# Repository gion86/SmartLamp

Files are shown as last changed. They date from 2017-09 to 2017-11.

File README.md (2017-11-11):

# SMART LAMP
### Smart lamp to wakeup with sunrise
##### Through hole version

The project is a LED strip control board to generate a smart wakeup light, which 
simulates the sunrise light.
On board there is a real time clock, to  keep track of the actual date and time 
even on power loss, and some MOSFET to drive the LEDs with PWM.
On a separate breakout board I'm using a BLE chipset to connect with an Android 
application, to setup date, time, alarms and LED light.

Everything is soldered on the same PCB. The micro is an Atmel ATTiny84.

The project is compiled for Atmel AVR, with standard AVR GCC toolchain. 
Eclipse was used to create and compile the projects, with the AVR Eclipse Plugin.

This project consists of a main C++ file and some libraries:

* **DS3232RTC** : real time clock library, to read the actual date and time. The sensors 
  library have been modified to work with the an external instance of the I2C bus 
  control class, and each functionality has been tested with the hardware. 
* **TimeZone** : Arduino library to account for DST (summer time) with the RTC clock. 
  The timezone rules are saved into an EEPROM image (to save program memory on the 
  ATTiny84): the image is in Intel HEX format.
  (reference <https://github.com/gion86/Timezone>, version with time.h from avr-libc).
* **USIWire** : Wire library for the small ATTiny, were the I2C management 
  hardware is not present. The library uses the internal USI hardware to communicate 
  over serial connection, and implement I2C protocol (reference <https://github.com/puuu/USIWire>).
* **ATTiny core**  (reference <https://github.com/gion86/ATTinyCore/tree/newduino> and 
  <https://github.com/SpenceKonde/ATTinyCore>)

The project folder contains:

* the bill of material;
* datasheet of used components;
* electrical schematic and board (made with Eagle);

Some pictures can be found at https://photos.app.goo.gl/nYQq9dkLF3Ui9xUt2

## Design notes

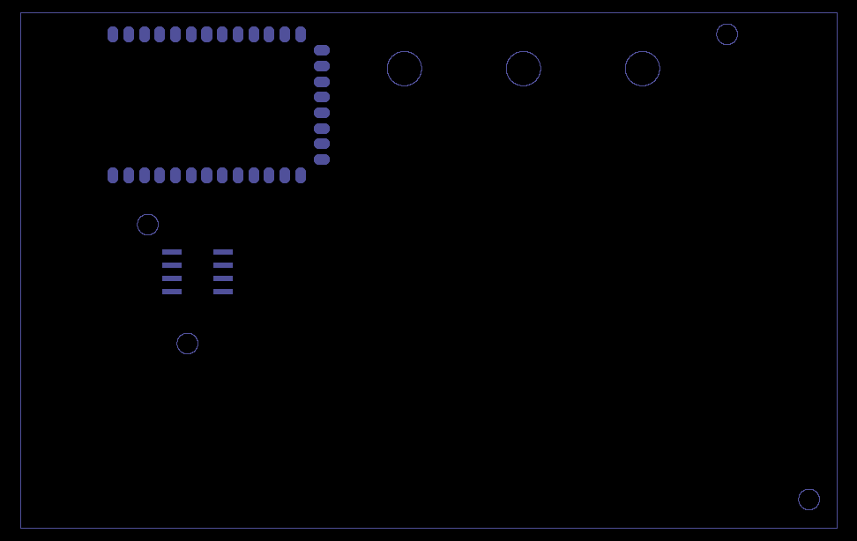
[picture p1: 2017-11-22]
Documentation/Schematics/SmartLamp/Gerber/PNGs/SmartLamp.GTP.png

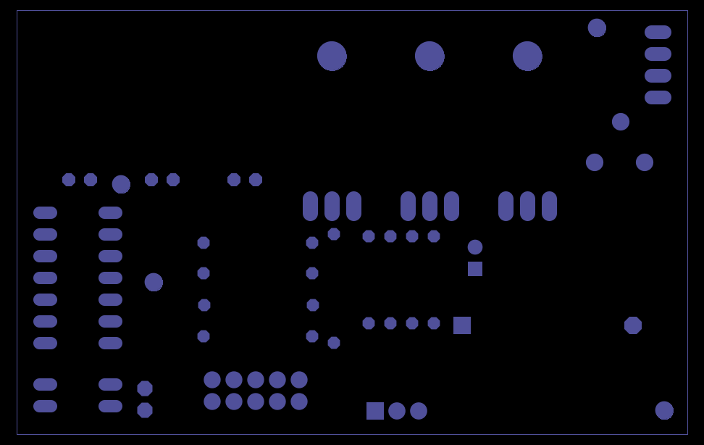
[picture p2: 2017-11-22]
Documentation/Schematics/SmartLamp/Gerber/PNGs/SmartLamp.GBS.png

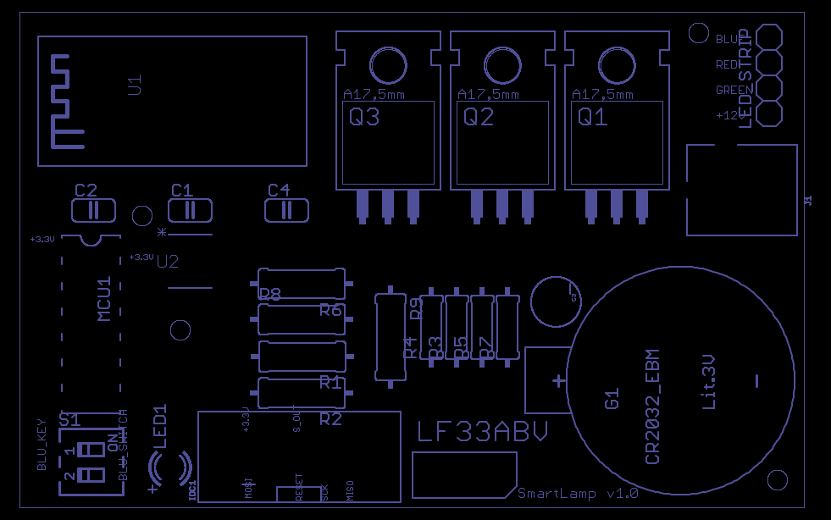
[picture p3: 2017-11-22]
Documentation/Schematics/SmartLamp/Gerber/PNGs/SmartLamp.GTO.png

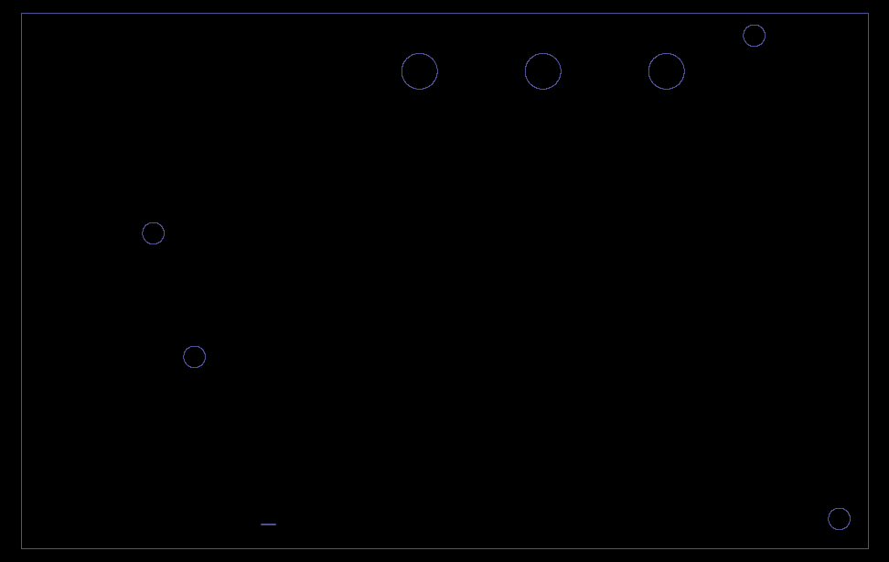
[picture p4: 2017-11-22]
Documentation/Schematics/SmartLamp/Gerber/PNGs/SmartLamp.GBO.png

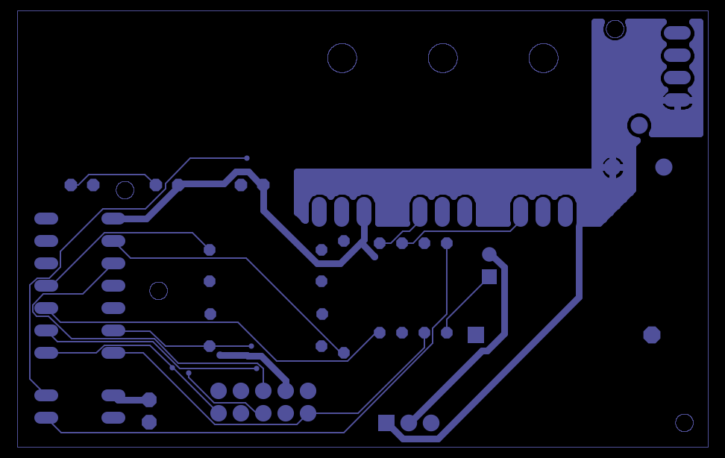
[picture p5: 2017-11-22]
Documentation/Schematics/SmartLamp/Gerber/PNGs/SmartLamp.GBL.png

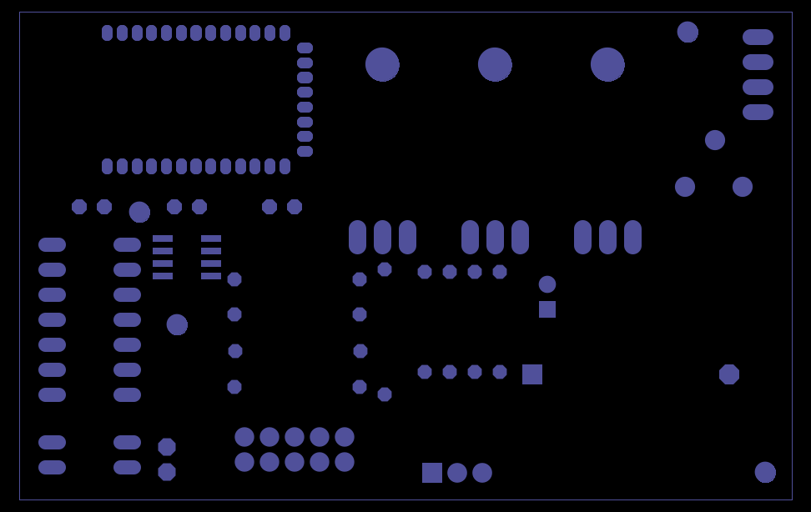
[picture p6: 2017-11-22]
Documentation/Schematics/SmartLamp/Gerber/PNGs/SmartLamp.GTS.png

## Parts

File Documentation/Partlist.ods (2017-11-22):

SMART LAMP - PROJECT BOM
Component | Value | Device | Package |  | Where | Price | Shipment Cost
Electronic
BT1 | BT1 | BATTERY-20MM_SMD_4LEGS | BATTCON_20MM_4LEGS | x | Amazon | € 0,18
BATTERY CR2032 |  |  |  | x
C1 | 0.1uF | C-US025-024X044 | C025-024X044 | x
C2 | 0.1uF | C-US025-024X044 | C025-024X044 | x
C4 | 0.1uF | C-US025-024X044 | C025-024X044 | x
C3 | 100uF | CAP_POLPTH2 | CPOL-RADIAL-10UF-25V | x
IC1 | DS3231/SO | DS3231/SO | SO16W | x | Maxim
IDC1 | IDC1 | CONN_05X2SHD | 2X5-SHROUDED | x
J1 | POWER_JACKPTH_BREAD | POWER_JACKPTH_BREAD | POWER_JACK_PTH_BREAD | x | Ebay | € 0,50
LED1 | GREEN | LED3MM | LED3MM | x
LF33ABV | LF33ABV | LF33ABV | TO254P450X1020X1935-3P | x
MCU1 | ATTINY84ATTINY84-20PU | ATTINY84ATTINY84-20PU | DIL14 | x
MCU SOCKET |  | 14 PIN DIP | 14 PIN DIP | x
Q1 | IRL44Z | IRL44Z | TO220BH | x | Ebay | € 1,30 | € 5,50
Q2 | IRL44Z | IRL44Z | TO220BH | x | Ebay | € 1,30
Q3 | IRL44Z | IRL44Z | TO220BH | x | Ebay | € 1,30
R1 | 10K | R-US_0309/12 | 0309/12 | x
R2 | 10K | R-US_0309/12 | 0309/12 | x
R3 | 220 | R-US_0207/10 | 0207/10 | x
R4 | 220 | R-US_0207/10 | 0207/10 | x
R5 | 220 | R-US_0207/10 | 0207/10 | x
R6 | 10K | R-US_0309/12 | 0309/12 | x
R7 | 1K | R-US_0207/10 | 0207/10 | x
R8 | 470 | R-US_0309/12 | 0309/12 | x
S1 | SD4-02 | SD4-02 | DIL/CODE SWITCH | x | Ebay | € 1,00
U1 | HM-10 | HM-10 | HM-10 |  | Ebay | € 1,89 | € 2,99
BOARD |  | PCB |  |  |  | € 4,50 | € 5,77
Construction
LED STRIP RGB | RGB 5050 5mt |  |  | x | Ebay | € 7,92 | € 7,00
LED STRIP CONNECTOR | Jack 4 pins RGB |  |  | x | Ebay | € 1,03
LED STRIP CABLE | RGB 1mt |  |  | x | Ebay | € 1,03
 |  |  |  |  |  | € 21,95 | € 21,26
 |  |  |  |  |  |  | TOTAL
 |  |  |  |  |  |  | € 43,21

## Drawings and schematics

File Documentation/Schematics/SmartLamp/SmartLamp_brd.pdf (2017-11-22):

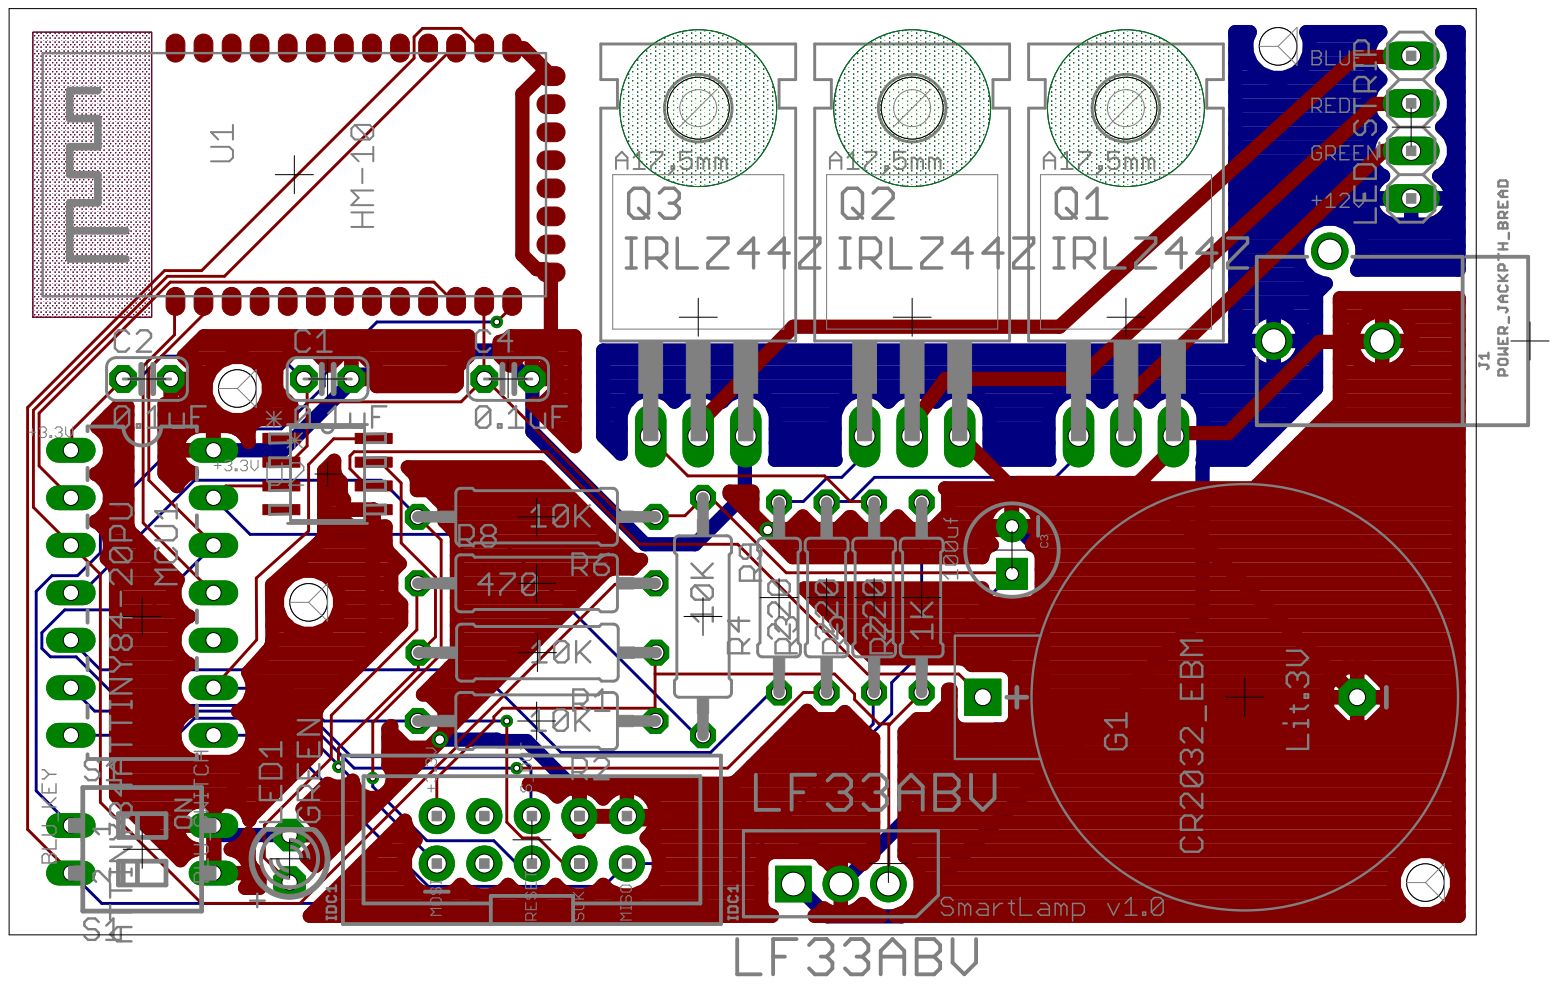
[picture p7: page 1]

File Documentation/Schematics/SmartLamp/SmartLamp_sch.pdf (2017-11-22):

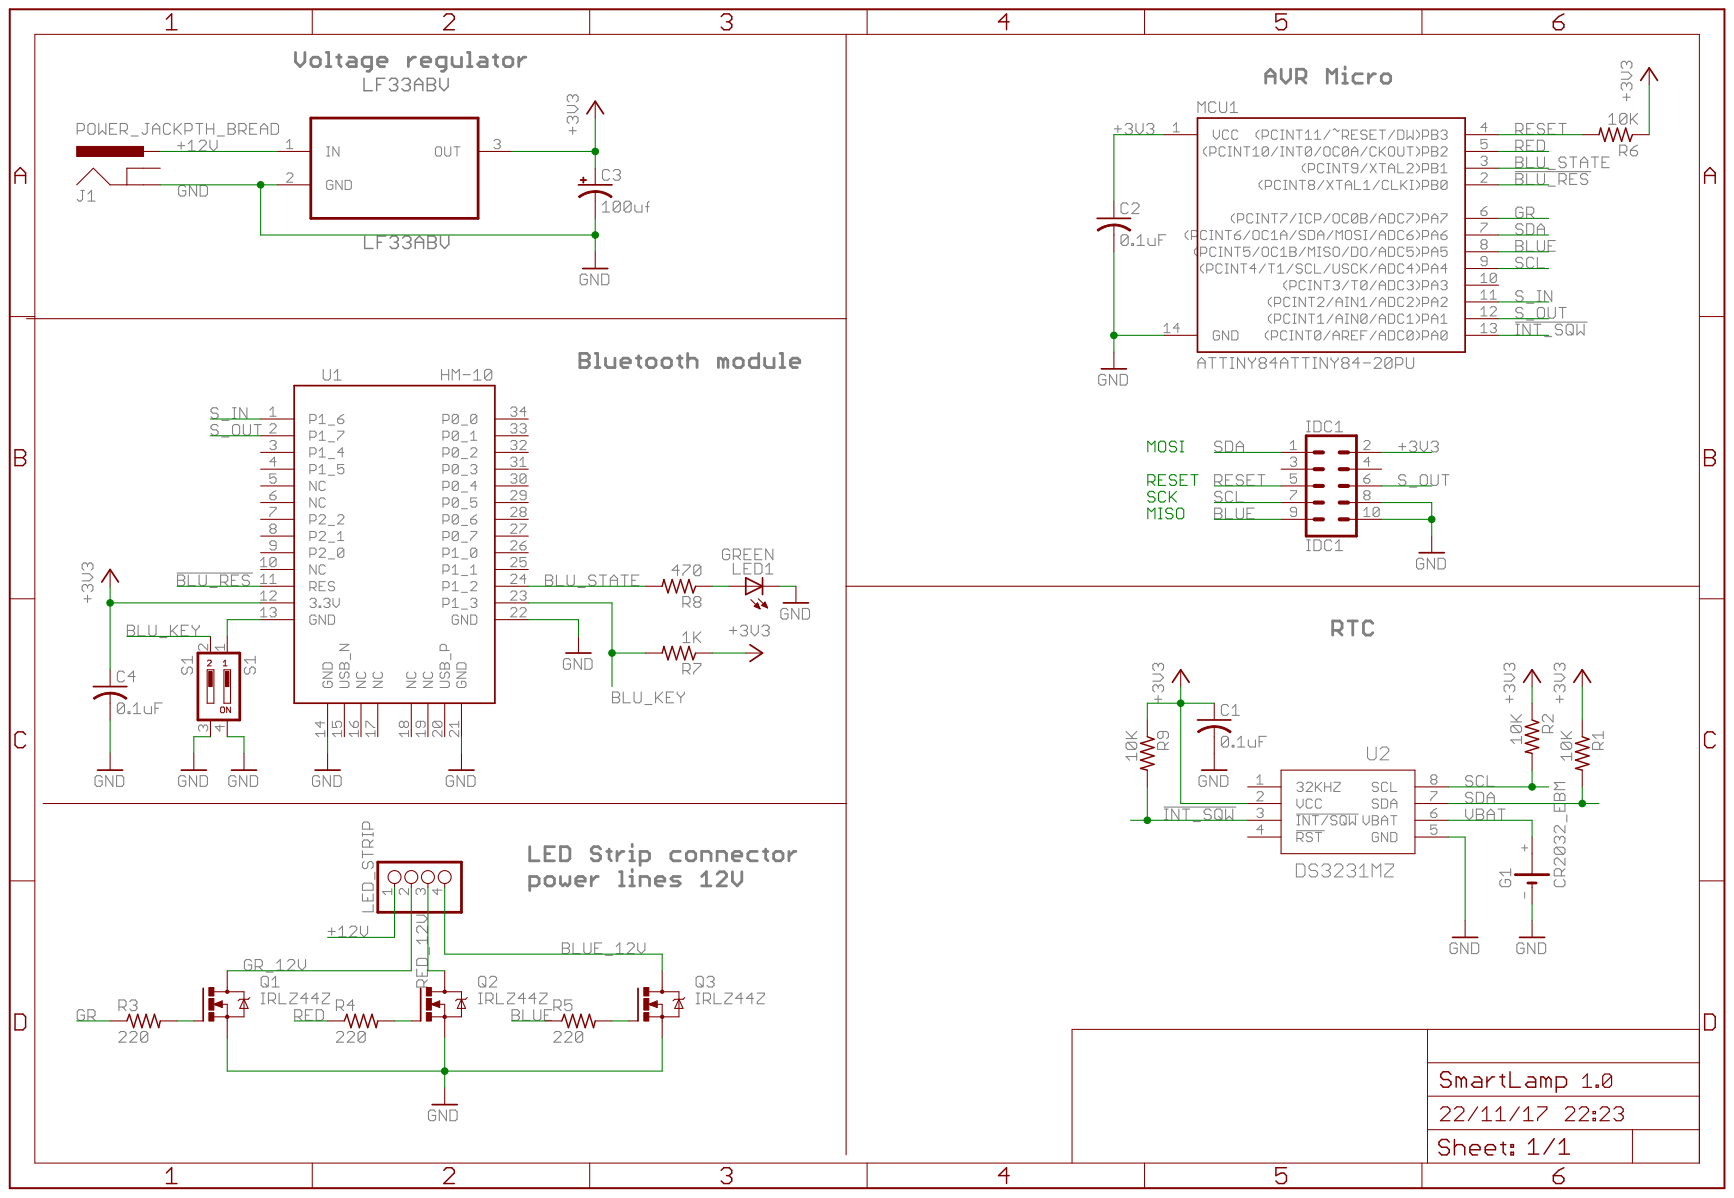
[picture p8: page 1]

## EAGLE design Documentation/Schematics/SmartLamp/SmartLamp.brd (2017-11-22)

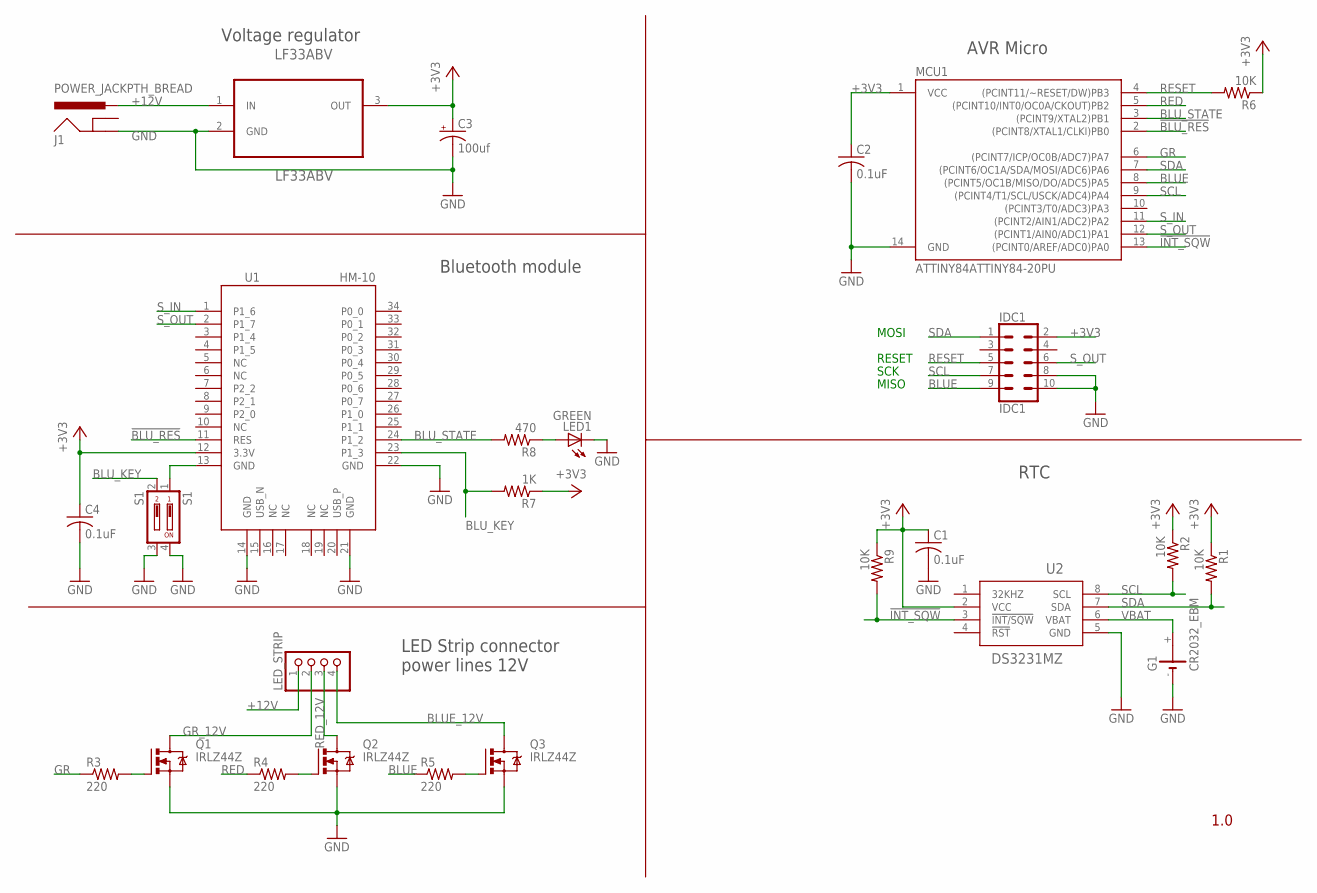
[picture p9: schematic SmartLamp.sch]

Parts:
C1, C2, C4: 0.1uF; C025-024X044
C3: 100uf; CPOL-RADIAL-10UF-25V
G1: CR2032_EBM
IDC1: IDC1; 2X5-SHROUDED
J1: POWER_JACKPTH_BREAD; POWER_JACK_PTH_BREAD
LED1: GREEN; LED3MM
LED_STRIP: PINHD-1X4; 1X04
LF33ABV: LF33ABV; TO254P450X1020X1935-3P
MCU1: ATTINY84ATTINY84-20PU; DIL14
Q1, Q2, Q3: IRLZ44Z; TO220BH
R1, R2, R6, R9: 10K; 0309/12
R3, R4, R5: 220; 0207/10
R7: 1K; 0207/10
R8: 470; 0309/12
S1: S1; SD4-02
U1: HM-10
U2: DS3231MZ; 21-0041B_8

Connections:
!BLU_RES: MCU1.2 ((PCINT8/XTAL1/CLKI)PB0), U1.11 (RES)
!INT_SQW: MCU1.13 ((PCINT0/AREF/ADC0)PA0), R9.2, U2.3 (!INT/SQW)
+3V3: C1.1, C2.1, C3.1 (+), C4.1, IDC1.2, LF33ABV.3 (OUT), MCU1.1 (VCC), R1.1, R2.1, R6.1, R7.1, R9.1, U1.12 (3.3V), U2.2 (VCC)
+12V: J1.PWR, LED_STRIP.1, LF33ABV.1 (IN)
BLUE: IDC1.9, MCU1.8 ((PCINT5/OC1B/MISO/DO/ADC5)PA5), R5.1
BLUE_12V: LED_STRIP.4, Q3.D
BLU_KEY: R7.2, S1.2, U1.23 (P1_3)
BLU_STATE: MCU1.3 ((PCINT9/XTAL2)PB1), R8.2, U1.24 (P1_2)
BLU_SWITCH: S1.1, U1.13 (GND)
GND: C1.2, C2.2, C3.2 (-), C4.2, G1.-, IDC1.8, IDC1.10, J1.GND, LED1.K (C), LF33ABV.2 (GND), MCU1.14 (GND), Q1.S, Q2.S, Q3.S, S1.3, S1.4, U1.14 (GND), U1.21 (GND), U1.22 (GND), U2.5 (GND)
GR: MCU1.6 ((PCINT7/ICP/OC0B/ADC7)PA7), R3.1
GR_12V: LED_STRIP.2, Q1.D
unnamed: Q1.G, R3.2
unnamed: Q2.G, R4.2
unnamed: LED1.A, R8.1
unnamed: Q3.G, R5.2
RED: MCU1.5 ((PCINT10/INT0/OC0A/CKOUT)PB2), R4.1
RED_12V: LED_STRIP.3, Q2.D
RESET: IDC1.5, MCU1.4 ((PCINT11/~RESET/DW)PB3), R6.2
SCL: IDC1.7, MCU1.9 ((PCINT4/T1/SCL/USCK/ADC4)PA4), R2.2, U2.8 (SCL)
SDA: IDC1.1, MCU1.7 ((PCINT6/OC1A/SDA/MOSI/ADC6)PA6), R1.2, U2.7 (SDA)
S_IN: MCU1.11 ((PCINT2/AIN1/ADC2)PA2), U1.1 (P1_6)
S_OUT: IDC1.6, MCU1.12 ((PCINT1/AIN0/ADC1)PA1), U1.2 (P1_7)
VBAT: G1.+, U2.6 (VBAT)

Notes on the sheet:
MOSI
SCK
MISO
RESET
RTC
AVR Micro
Voltage regulator
Bluetooth module
LED Strip connector power lines 12V

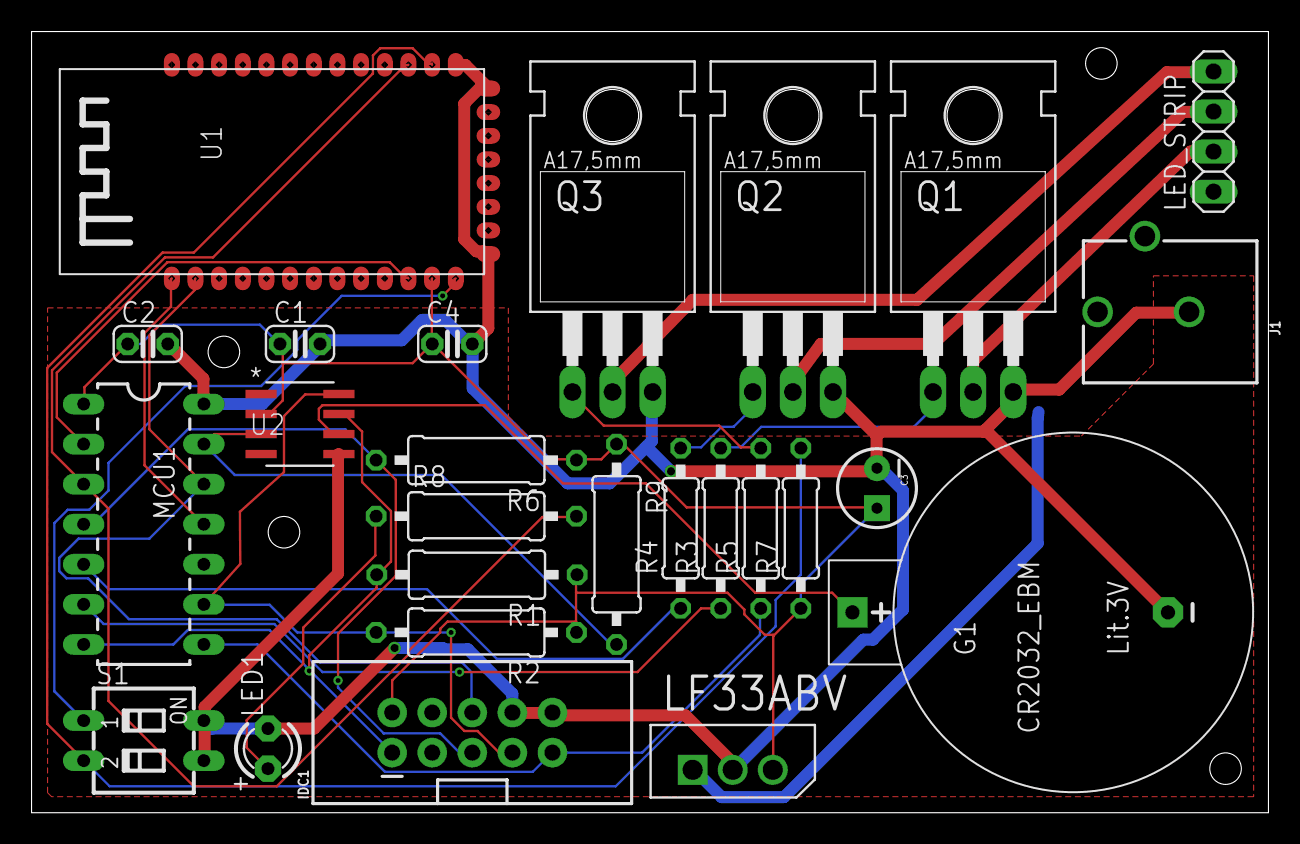
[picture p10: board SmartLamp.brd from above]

Board: 2 copper layers, 78.4 x 49.5 mm, 26 parts (0 on the bottom side), 24 nets.

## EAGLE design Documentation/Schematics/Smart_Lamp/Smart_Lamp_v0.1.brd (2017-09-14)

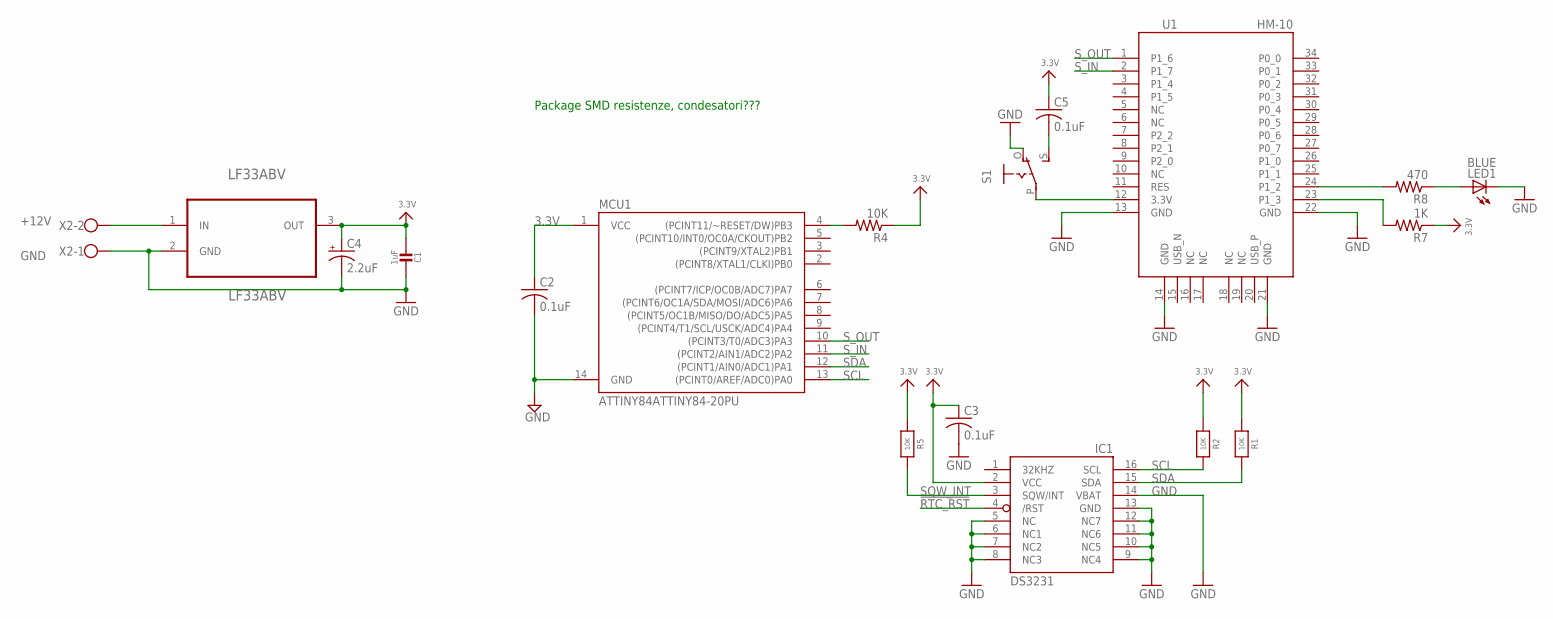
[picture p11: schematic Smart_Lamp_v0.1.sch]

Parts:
C1: 1uF; 0805-NO
C2, C5: 0.1uF; C025-024X044
C3: 0.1uF; C0805
C4: 2.2uF; CPOL-RADIAL-10UF-25V
IC1: DS3231/SO; SO16W
LED1: BLUE; LED3MM
LF33ABV: LF33ABV; TO254P450X1020X1935-3P
MCU1: ATTINY84ATTINY84-20PU; DIL14
R1, R2, R5: 10K; 0805-NO
R4: 10K; 0207/10
R7: 1K; 0207/10
R8: 470; 0207/10
S1: EG1218S; EG1218
U1: HM-10
X2: W237-102

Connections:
3.3V: C1.2, C2.1, C3.1, C4.1 (+), C5.1, IC1.2 (VCC), LF33ABV.3 (OUT), MCU1.1 (VCC), R1.1, R2.1, R4.1, R5.1, R7.1
!RTC_RST: IC1.4 (/RST)
+12V: LF33ABV.1 (IN), X2.2
GND: C1.1, C2.2, C3.2, C4.2 (-), IC1.5 (NC), IC1.6 (NC1), IC1.7 (NC2), IC1.8 (NC3), IC1.9 (NC4), IC1.10 (NC5), IC1.11 (NC6), IC1.12 (NC7), IC1.13 (GND), IC1.14 (VBAT), LED1.K (C), LF33ABV.2 (GND), MCU1.14 (GND), S1.O, U1.13 (GND), U1.14 (GND), U1.21 (GND), U1.22 (GND), X2.1
unnamed: S1.P, U1.12 (3.3V)
unnamed: C5.2, S1.S
unnamed: MCU1.4 ((PCINT11/~RESET/DW)PB3), R4.2
unnamed: R8.2, U1.24 (P1_2)
unnamed: LED1.A, R8.1
unnamed: R7.2, U1.23 (P1_3)
SCL: IC1.16 (SCL), MCU1.13 ((PCINT0/AREF/ADC0)PA0), R2.2
SDA: IC1.15 (SDA), MCU1.12 ((PCINT1/AIN0/ADC1)PA1), R1.2
SQW_INT: IC1.3 (SQW/INT), R5.2
S_IN: MCU1.11 ((PCINT2/AIN1/ADC2)PA2), U1.2 (P1_7)
S_OUT: MCU1.10 ((PCINT3/T0/ADC3)PA3), U1.1 (P1_6)

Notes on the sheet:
Package SMD resistenze, condesatori???

Board: 2 copper layers, 18 parts (0 on the bottom side), 14 nets, no tracks yet.

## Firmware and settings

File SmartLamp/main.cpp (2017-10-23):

/*
 *  This file is part of SmartLamp application.
 *
 * Licensed under the Apache License, Version 2.0 (the "License");
 * you may not use this file except in compliance with the License.
 * You may obtain a copy of the License at
 *
 *    http://www.apache.org/licenses/LICENSE-2.0
 *
 * Unless required by applicable law or agreed to in writing, software
 * distributed under the License is distributed on an "AS IS" BASIS,
 * WITHOUT WARRANTIES OR CONDITIONS OF ANY KIND, either express or implied.
 * See the License for the specific language governing permissions and
 * limitations under the License.
 *
 */

/*
 * Built for Attiny84 8Mhz, using AVR USBasp programmer.
 * VERSION 0.3
 */

#include <avr/io.h>
#include <avr/sleep.h>
#include <avr/pgmspace.h>
#include <time.h>

#include <Arduino.h>

#include <USIWire.h>
#include <Timezone.h>
#include <DS3232RTC.h>

// Input/output defines
#define LED_RED             2   // RGB strip: red pin
#define LED_GR              3   // RGB strip: green pin
#define LED_BLUE            5   // RGB strip: blue pin

#define BLU_STATE           1   // Bluetooth module state pin
#define BLU_RESET           0   // Bluetooth module reset pin

#define RTC_INT_SQW        10   // INT/SQW pin from RTC

// I2C defines
#define SDA                 4   // SDA pin
#define SCL                 6   // SCL pin

// Serial defines
#define SERIAL_BAUD      9600   // For at mode and for data mode (CC41, HM-10 and MLT-BT05)

#define SLEEP_TIMEOUT  10000L   // TODO Timeout before sleep

#define LENGTH             40   // Command buffer length

#define RULES_TZ_ADD        0   // Timezone rules EEPROM start address

#define PERIOD          30000   // LED crossfade total duration
#define MAX_ANALOG_V       50   // Analog output max value for RGB

#define STEP_START         0
#define STEP_READ_CMD      10
#define STEP_FADE          15

// Global constants
// CET Time Zone (Rome, Berlin) -> UTC/GMT + 1
// These rules are written in the EEPROM, at address RULES_TZ_ADD. The EEPROM by default gets erased by the
// erase procedure on upload, which clears FLASH, EEPROM and lock bits. To preserve the EEPROM memory fuse
// EESAVE has to be set. In this case EEPROM will not be erased during erase procedure.
// But the fuse has to be cleared if you want to clear and/or reflash EEPROM.
//const TimeChangeRule CEST = {"CEST", Last, Sun, Mar, 2, 120};     // Central European Summer Time (DST)
//const TimeChangeRule CET  = {"CET ", Last, Sun, Oct, 3, 60};      // Central European Standard Time

// Global variables
USIWire bus;                    // USIWire instance (I2C bus)
DS3232RTC RTC(bus);             // DS3232 RTC instance (I2C bus)

bool data = false;
unsigned long prevMillis = 0;   // Millis counter to sleep
bool rtcInitOk = false;         // Communication OK with RTC

Timezone myTZ(RULES_TZ_ADD);    // Constructor to read rules stored at EEPROM address RULES_TZ_ADD
//Timezone myTZ(CET, CEST);     // Constructor to build object with TimeChangeRule

TimeChangeRule *tcr;            // Pointer to the time change rule, use to get TZ abbreviations

uint8_t step = STEP_START;

// Put the micro to sleep
void system_sleep() {
  set_sleep_mode(SLEEP_MODE_PWR_DOWN);
  sleep_enable();
  sleep_mode();

  // sleeping ...
  sleep_disable(); // wake up fully
}

/*
 * Converts the date/time to standard Unix epoch format, using time.h library (avr-libc)
 *
 * Param:
 * - int16_t YYYY: year (given as ex. 2017)
 * - int8_t MM: month [1, 12]
 * - int8_t DD: day of the month [1, 31]
 * - int8_t hh: hour [0, 23]
 * - int8_t mm: minute [0, 59]
 * - int8_t ss: second [0, 59]
 */
time_t tmConvert_t(int16_t YYYY, int8_t MM, int8_t DD, int8_t hh, int8_t mm, int8_t ss) {
  struct tm tm;
  tm.tm_year = YYYY - 1900 + 30;    // avr-libc time.h: years since 1900 + y2k epoch difference (2000 - 1970)
  tm.tm_mon  = MM - 1;              // avr-libc time.h: months in [0, 11]
  tm.tm_mday = DD;
  tm.tm_hour = hh;
  tm.tm_min  = mm;
  tm.tm_sec  = ss;
  return mk_gmtime(&tm);
}

void printDigits(int digits) {
  Serial.print(':');
  if (digits < 10)
    Serial.print('0');
  Serial.print(digits);
}

void digitalClockDisplay(time_t time, const char *tz = NULL) {
  struct tm tm;

  gmtime_r(&time, &tm);

  // Digital clock display of the time
  Serial.print(tm.tm_hour);
  printDigits(tm.tm_min);
  printDigits(tm.tm_sec);
  Serial.print(' ');
  Serial.print(tm.tm_mday);
  Serial.print('/');
  Serial.print(tm.tm_mon + 1);              // avr-libc time.h: months in [0, 11]
  Serial.print('/');
  Serial.print(tm.tm_year + 1900 - 30);     // avr-libc time.h: years since 1900 + y2k epoch difference (2000 - 1970)

  if (tz != NULL) {
    Serial.print(' ');
    Serial.print(tz);
  }

  Serial.println();
}

// PCINT Interrupt Service Routine (unused)
ISR(PCINT0_vect) {
  // Don't do anything here but we must include this
  // block of code otherwise the interrupt calls an
  // uninitialized interrupt handler.
}

// ========================================================
// |                        SETUP                         |
// ========================================================

void setup() {
  uint8_t retcode;

  OSCCAL = 0x86;                    // Calibrated OSSCAL value with TinyTuner

  Serial.begin(SERIAL_BAUD);
  bus.begin();

  // Pinmode set
  pinMode(LED_BLUE, OUTPUT);
  pinMode(LED_GR, OUTPUT);
  pinMode(LED_RED, OUTPUT);
  pinMode(BLU_STATE, INPUT);
  pinMode(BLU_RESET, OUTPUT);
  pinMode(RTC_INT_SQW, INPUT);

  time_t t;
  t = tmConvert_t(2017, 10, 25, 11, 00, 00);

  if ((retcode = RTC.set(t)) == 0)
    rtcInitOk = true;
  else {
    Serial.print(F("RTC err: "));
    Serial.println(retcode);
  }

  time_t utc = RTC.get();
  Serial.print(F("UTC: "));
  digitalClockDisplay(utc, "UTC");

  time_t local = myTZ.toLocal(utc, &tcr);
  Serial.print(F("Local: "));
  digitalClockDisplay(local, tcr->abbrev);

  // Power settings
  ADCSRA  = 0;                      // Disable ADC to save power
  MCUCR  |= _BV(BODS);              // BOD disabled

  PCMSK0 |= _BV(PCINT0);            // Pin change mask: listen to portA bit 0 (D10) (RTC_INT_SQW)
  PCMSK0 |= _BV(PCINT2);            // Pin change mask: listen to portA bit 2  (D8) (Serial RX - AIN1)
  GIMSK  |= _BV(PCIE0);             // Enable PCINT interrupt on portA
}

// ========================================================
// |                        LOOP                          |
// ========================================================

void loop() {
  size_t count = 0;
  char buffer[LENGTH];

  uint8_t value;
  double x = 0;

  switch (step) {
    case STEP_START:

      // FIXME Wake from sleep with new CORE can't read first serial bytes....
      if (millis() - prevMillis >= SLEEP_TIMEOUT) {
        prevMillis = millis();
        Serial.println(F("Sleeping..."));
        system_sleep();
        Serial.println(F("Waking up..."));
        digitalClockDisplay(RTC.get(), "UTC");

        // Necessary to reset the alarm flag on RTC!
        if (RTC.alarm(ALARM_1)) {
          Serial.println(F("From alarm..."));
        }

        step = STEP_READ_CMD;
      }

      break;

    case STEP_READ_CMD:

      while (Serial.available() && count < LENGTH - 1) {
        delay(2);
        char c = (char) Serial.read();

        prevMillis = millis();      // Update prevMillis to reset sleep timeout

        if (c == '\r' || c == '\n') {
          if (c == '\n') {
            data = true;
            Serial.flush();
            break;
          }
          continue;
        }

        buffer[count] = c;
        count++;
      }

      if (data) {
        buffer[count] = '\0';
        //Serial.print("COUNT = ");
        //Serial.println(count);
        Serial.println(buffer);

        count = 0;
        data = false;

        if (strcmp(buffer, "ON") == 0) {
          RTC.setAlarm(ALM1_MATCH_MINUTES, 00, 10, 23, 0);
          RTC.alarmInterrupt(ALARM_1, true);

          step = STEP_FADE;
        }
        else if (strcmp(buffer, "OFF") == 0) {
          analogWrite(LED_BLUE, 0);
          analogWrite(LED_RED, 0);
          analogWrite(LED_GR, 0);
        }

        //    time_t utc = RTC.get();
        //    Serial.print(F("UTC: "));
        //    digitalClockDisplay(utc, "UTC");
        //
        //    time_t local = myTZ.toLocal(utc, &tcr);
        //    Serial.print(F("Local: "));
        //    digitalClockDisplay(local, tcr->abbrev);
      }
      break;

    case STEP_FADE:

      x = (millis() % PERIOD) / (double) PERIOD;
      value = MAX_ANALOG_V * sin(PI * x);

      //  Serial.print(F("t: "));
      //  Serial.print(millis());
      Serial.print(F(", x: "));
      Serial.print(x);
      Serial.print(F(", c: "));
      Serial.println(value);

      analogWrite(LED_BLUE, value);
      analogWrite(LED_RED, value);
      analogWrite(LED_GR, value);

      break;

    default:
      break;
  }
}

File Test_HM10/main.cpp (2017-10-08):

/*
 * Test and query program for the HM-10 BLE module.
 * Derived in most part from https://github.com/ayavilevich/arduino-ble-ident-n-set
 *
 * To be used with Arduino (Uno)
 */

#include <Arduino.h>
#include <SoftwareSerial.h>

/// Consts
// BLE module default pins
#define LED_PIN             4
#define RX_PIN              8
#define TX_PIN              9
#define STATE_PIN           7
#define STATE_PIN_MISSING  -1

// misc
#define SERIAL_BAUD      9600
#define SERIAL_TIMEOUT  60000   // 1 min
#define BLE_BAUD         9600   // for at mode and for data mode (CC41, HM-10 and MLT-BT05)
#define BLE_TIMEOUT       250   // 100 was ok for CC41 and HM-10 but not for MLT_BT05's AT+HELP command
#define INITIAL_DELAY     200

enum ModuleType {
  HM10, CC41, MLT_BT05, Unknown
};
enum Operation {
  Quit, SetName, SetPass, SetStateBehavior, SetPower, DisplayMainSettings
};

/// State
SoftwareSerial * ble = NULL;
int rxPin, txPin, statePin;
ModuleType moduleType;

/// Special functions
// define here due to custom return type
ModuleType identifyDevice();
void doCommandAndEchoResult(const char * command, const __FlashStringHelper * meaning = NULL);

// Serial line end modes
// CR \r
// LF \n
// CR&LF \r\n

/// Interface helper functions

int getLengthWithoutTerminator(String & s) {
  int l = s.length();
  if (l == 0)
    return 0;
  if (s.charAt(l - 1) == '\r')
    return l - 1;
  return l;
}

int readInt(const __FlashStringHelper * message, int defaultValue) {
  Serial.print(message);
  Serial.print(" [");
  Serial.print(defaultValue);
  Serial.println("] :");

  String s = Serial.readStringUntil('\n');
  if (getLengthWithoutTerminator(s) == 0)
    return defaultValue;
  return s.toInt();
}

String readString(const __FlashStringHelper * message,
    const __FlashStringHelper * defaultValue) {
  Serial.print(message);
  Serial.print(" [");
  Serial.print(defaultValue);
  Serial.println("] :");

  String s = Serial.readStringUntil('\n');
  int l = getLengthWithoutTerminator(s);
  if (l == 0)
    return defaultValue;
  s.remove(l); // remove terminator
  return s;
}

ModuleType identifyDevice() {
  Serial.println(F("Detecting module type"));

  // check for HM-10
  ble->print("AT");
  String s = ble->readString();

  if (s.length() == 2 && s.compareTo("OK") == 0) {
    Serial.println(F("HM-10 detected!"));
    return HM10;
  } else if (s.length() == 0) {

    // check for CC41
    ble->println("");
    s = ble->readString();

    if (s.length() == 4 && s.compareTo("OK\r\n") == 0) {

      Serial.println(F("CC41 detected!")); // An HM-10 clone
      return CC41;
    } else if (s.length() == 0) {

      // check for MLT_BT05
      ble->println("AT");
      s = ble->readString();
      if (s.length() == 4 && s.compareTo("OK\r\n") == 0) {
        Serial.println(F("MLT-BT05 detected!")); // An HM-10 clone
        return MLT_BT05;
      } else if (s.length() == 0) {
        Serial.println(F("No response received from module."));
        Serial.println(F("Verify that the module is powered. Is the led blinking?"));
        Serial.println(F("Check that pins are correctly connected and the right values were entered."));
        Serial.println(F("Are you using a logic voltage converter for a module that already has such logic on board?"));
        Serial.println(F("Are you using a module that expects 3.3v logic? You might need to do logic convertion on Arduino's TX pin (module's RX pin)."));
      } else {
        Serial.print(F("Unexpected result of length="));
        Serial.println(s.length());
        Serial.println(s);
      }
    } else {
      Serial.print(F("Unexpected result of length="));
      Serial.println(s.length());
      Serial.println(s);
    }
  } else {
    Serial.print(F("Unexpected result of length="));
    Serial.println(s.length());
    Serial.println(s);
  }
  return Unknown;
}

bool determineConnectionState() {
  if (statePin != STATE_PIN_MISSING) {
    Serial.println(F("Checking module state..."));
    // read state
    int state = digitalRead(statePin);
    // check if state is "blinking"
    unsigned long p1 = pulseIn(statePin, HIGH, 2000000);
    unsigned long p2 = pulseIn(statePin, LOW, 2000000);
    if (p1 == p2 && p1 == 0) {
      if (state == HIGH) {
        Serial.println(F("The signal on the state pin is HIGH. This means the device is connected and is in data mode. Sketch can't proceed."));
        return false;
      } else Serial.println(F("The signal on the state pin is LOW. This means the device is not connected and is in command mode."));
    }
    else // blinking
    {
      Serial.println(F("The signal on the state pin is \"blinking\". This usually means the device is not connected and is in command mode."));
      Serial.println(F("Consider reconfiguring the device to pass the state as-is. So it is simple to detect the state."));
    }
  } else {
    Serial.println(F("For this sketch, make sure the module is not connected to another BLE device."));
    Serial.println(F("This will make sure the device is in command mode."));
    Serial.println(F("A led on the module should be off or blinking."));
  }
  return true;
}

void openBLE() {
  Serial.print(F("Opening serial connection to BLE module at pins: "));
  Serial.print(RX_PIN);
  Serial.print(F(", "));
  Serial.print(TX_PIN);
  Serial.print(F(", "));
  Serial.print(STATE_PIN);
  Serial.println();

  rxPin = RX_PIN;
  txPin = TX_PIN;
  statePin = STATE_PIN;

  // open and create object
  ble = new SoftwareSerial(RX_PIN, TX_PIN);
  ble->begin(BLE_BAUD);
  ble->setTimeout(BLE_TIMEOUT);

  if (statePin != STATE_PIN_MISSING)
    pinMode(statePin, INPUT);
}
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

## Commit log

2017-09-13 Added first version of Eagle schematics
    [Smart_Lamp_v0.1.sch]
2017-09-13 Added regulator and bluetooth module to schematic
    [Smart_Lamp_v0.1.brd, Smart_Lamp_v0.1.sch]
2017-09-14 Small changes to schematic
    [Smart_Lamp_v0.1.brd, Smart_Lamp_v0.1.sch]
2017-09-16 Complete first version of schematic and board. Added first partlist and BOM
    [Partlist.ods, SmartLamp_v0.2.brd, SmartLamp_v0.2.sch]
2017-09-17 Added battery holder and IDC connector from Sparkfun
    [SmartLamp_v0.2.brd]
2017-09-17 Modified switch and RGB connection
    [Partlist.ods, SmartLamp_v0.2.brd, SmartLamp_v0.2.sch]
2017-09-18 Fixed IDC connector and replaced switch
    [SmartLamp_v0.2.brd, SmartLamp_v0.2.sch]
2017-09-18 Revisited board, ERC on schematic
    [SmartLamp_v0.2.brd, SmartLamp_v0.2.sch]
2017-09-20 Added datasheets of choosen components, first schematic with BOM
    [Partlist.ods, SmartLamp.brd, SmartLamp.sch]
2017-09-24 Added datasheet, replaced 2.2uf cap on schematic with 100uf, to program the Tiny at 3.3v. Added Arduino communication test with HM-10 module.
    [Partlist.ods, SmartLamp.brd, SmartLamp.sch]
2017-09-24 Updated partlist
    [Partlist.ods]
2017-09-26 Replaced SMD resistors with TH, for this version of the board.
    [Partlist.ods, SmartLamp.brd, SmartLamp.sch]
2017-09-28 Replaced RTC device, battery holder and switch, parts to buy..
    [Partlist.ods, SmartLamp.brd, SmartLamp.sch]
2017-10-01 Added datasheet for new mosfet IRLZ44n, small changes to HM-10 test program.
    [Partlist.ods, SmartLamp.brd, SmartLamp.sch]
2017-10-05 Changed dip switch to cut GND instead of VCC to bluetooth module.
    [SmartLamp.brd, SmartLamp.sch]
2017-10-07 Updated partlist and schematic. Added first version of application code: only reading and writing from BLE software serial.
    [Partlist.ods]
2017-10-08 Fixed IO connections to micro, in schematic and main.cpp
    [SmartLamp.brd, SmartLamp.sch]
2017-10-08 Fixed IO connections to micro, in schematic.
2017-10-08 Fixed cap on HM-10 module...
    [SmartLamp.brd, SmartLamp.sch]
2017-10-08 Fixed project reference, added calibrated OSSCAL value in main.
    [main.cpp]
2017-10-11 Fixed 3.3V path in schematic
    [SmartLamp.brd, SmartLamp.sch]
2017-10-12 Added pullup on SQW pin
    [SmartLamp.brd, SmartLamp.sch]
2017-10-14 Fixed project references. Changed reference to include NeoSWSerial library instead of SoftwareSerial. Changed serial parsing code: it seems more reliable now...
    [main.cpp]
2017-10-16 Fixed input/output pins and synch with schematic. Added PCINT interrupt on INT_SQW line from RTC
    [SmartLamp.brd, SmartLamp.sch]
2017-10-16 Removed SoftwareSerial library! Used CORE Serial instead. Fixed ISR(PCINT0_vect) call, enable PCINT0 and PCINT2 interrupt. Reviewed input/output pins.
    [SmartLamp.brd, SmartLamp.sch]
2017-10-17 Fixed output pins to use PWM... ops. Added PWM test cycle.
    [SmartLamp.brd, SmartLamp.sch]
2017-10-18 First tests with RTC and DS3232RTC and TinyWireM libraries. Added set times, added Alarms, tested wakeup from INT pin (RTC).
2017-10-20 Changed I2C library to USIWire (master-slave), removed -fpack-struct flag to avoid warning (same compile size).
    [main.cpp]
2017-10-21 Added comments, modified time and date print function. TimeZoneRule could be read from EEPROM..
2017-10-21 Fixed IDC connection (ISP programmer). Completed routing, added ground and signal plane.
2017-10-21 Added text in silk, added gerber files.
    [SmartLamp.GBL, SmartLamp.GBO, SmartLamp.GBP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]
2017-10-22 Changed position of dec capacitor on brd
    [SmartLamp.brd]
2017-10-22 Changed GND traces width, modified ground and power planes.
    [SmartLamp.brd, SmartLamp.sch]
2017-11-22 Schematic anb board v1.0: gerber file and png generated.
    [Partlist.ods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]
2017-11-22 Updated partlist with pcb board.
    [Partlist.ods]

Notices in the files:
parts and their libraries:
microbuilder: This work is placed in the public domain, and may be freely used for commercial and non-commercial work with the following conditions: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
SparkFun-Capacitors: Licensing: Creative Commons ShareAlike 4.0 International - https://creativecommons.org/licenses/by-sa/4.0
